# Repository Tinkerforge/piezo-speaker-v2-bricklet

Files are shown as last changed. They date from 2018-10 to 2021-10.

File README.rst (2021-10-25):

Piezo Speaker Bricklet 2.0
==========================

This repository contains the firmware source code and the hardware design
files. The documentation generator configs can be found at
https://github.com/Tinkerforge/generators

Repository Content
------------------

software/:
 * examples/: Examples for all supported languages
 * build/: Compiled files
 * src/: Source code of firmware
 * Makefile: Makefile to build project

hardware/:
 * Contains KiCad project files and additionally schematics as PDF

datasheets/:
 * Contains datasheets for sensors and complex ICs that are used

Hardware
--------

The hardware is designed with the open source EDA Suite KiCad
(http://www.kicad.org). Before you are able to open the files,
you have to install the Tinkerforge kicad-libraries
(https://github.com/Tinkerforge/kicad-libraries). You can either clone
them directly in hardware/ or clone them in a separate folder and
symlink them into hardware/
(ln -s kicad_path/kicad-libraries project_path/hardware). After that you
can open the .pro file in hardware/ with KiCad and from there view and
modify the schematics and the PCB layout.

Software
--------

If you want to do your own Brick/Bricklet firmware development we highly
recommend that you use our build environment setup script and read the
tutorial (https://www.tinkerforge.com/en/doc/Tutorials/Tutorial_Build_Environment/Tutorial.html).

To compile the C code we recommend you to install the newest GNU Arm Embedded
Toolchain (https://launchpad.net/gcc-arm-embedded/+download).
You also need to install bricklib2 (https://github.com/Tinkerforge/bricklib2).

You can either clone it directly in software/src/ or clone it in a
separate folder and symlink it into software/src/
(ln -s bricklib_path/bricklib2 project_path/software/src/). Finally make sure to
have CMake installed (http://www.cmake.org/cmake/resources/software.html).

After that you can build the firmware by invoking make in software/.
The firmware (.zbin) can then be found in software/build/ and uploaded
with brickv (click button "Flashing" on start screen).

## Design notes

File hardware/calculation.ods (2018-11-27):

LD1117
R (Ohm) | VOUT (V)
1000 | 5,0
470 | 3,0
220 | 2,1
100 | 1,6
LMR62014
R (Ohm) | VOUT (V)
34000 | 5,6
17000 | 9,9
11333,3333333333 | 14,3
8500 | 18,6

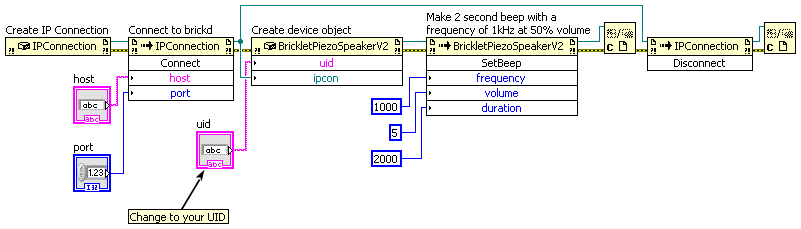
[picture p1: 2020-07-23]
software/examples/labview/Example Beep.vi.png

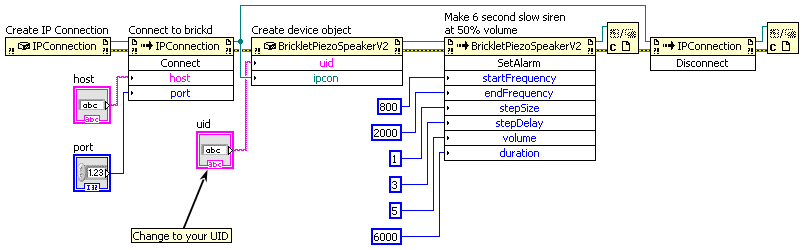
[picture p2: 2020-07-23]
software/examples/labview/Example Alarm.vi.png

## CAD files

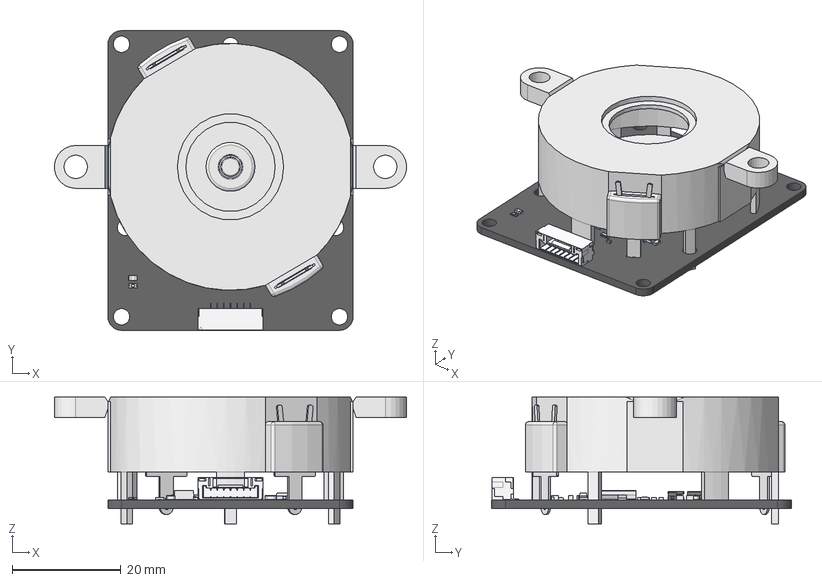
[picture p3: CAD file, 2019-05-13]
hardware/piezo-speaker-v2.FCStd
64.6 x 55.0 x 23.2 mm
Pcb
P4_PT_4532PLQ002_cp_5B86C3A8
C6_C_0603_5B86C852
C5_C_0805_5B86C837
C4_C_0603_5B86C222
C1_C_0402_5B86C258
C2_C_0805_5B86C2EB
C3_C_0603_5B86C321
C7_C_0805_5B86C0ED
C8_C_0603_5B86C4B9
C9_C_0805_5B86C3DE
C10_C_0805_5B86C2D0
D1_D_0603_blue_5B867174
D3_SOD-123_5B86C48A
L1_C_0603_5B86C7F5
L2_NR303_5B86C165
P1_BrickletConn_7pin_5B8671D7
R1_R_0603_5B86C6ED
R2_R_0603_5B86C69F
R3_R_0603_5B86C594
R4_R_0603_5B86C180
RP1_Cut_5B86C1A1
U1_QFN-24_4x4mm_Pitch0.5mm_5B86C357
U2_SOT-223_5B86C281
U3_SOT-23-5_5B86C10B
Q101_SOT23_5BD9AEDA
R101_R_0603_5BD9AEE4
R102_R_0603_5C406949
R103_R_0603_5C406953
R104_R_0603_5C40695D
R105_R_0603_5C406967
RP3_R_4x0603_5C40FF1B

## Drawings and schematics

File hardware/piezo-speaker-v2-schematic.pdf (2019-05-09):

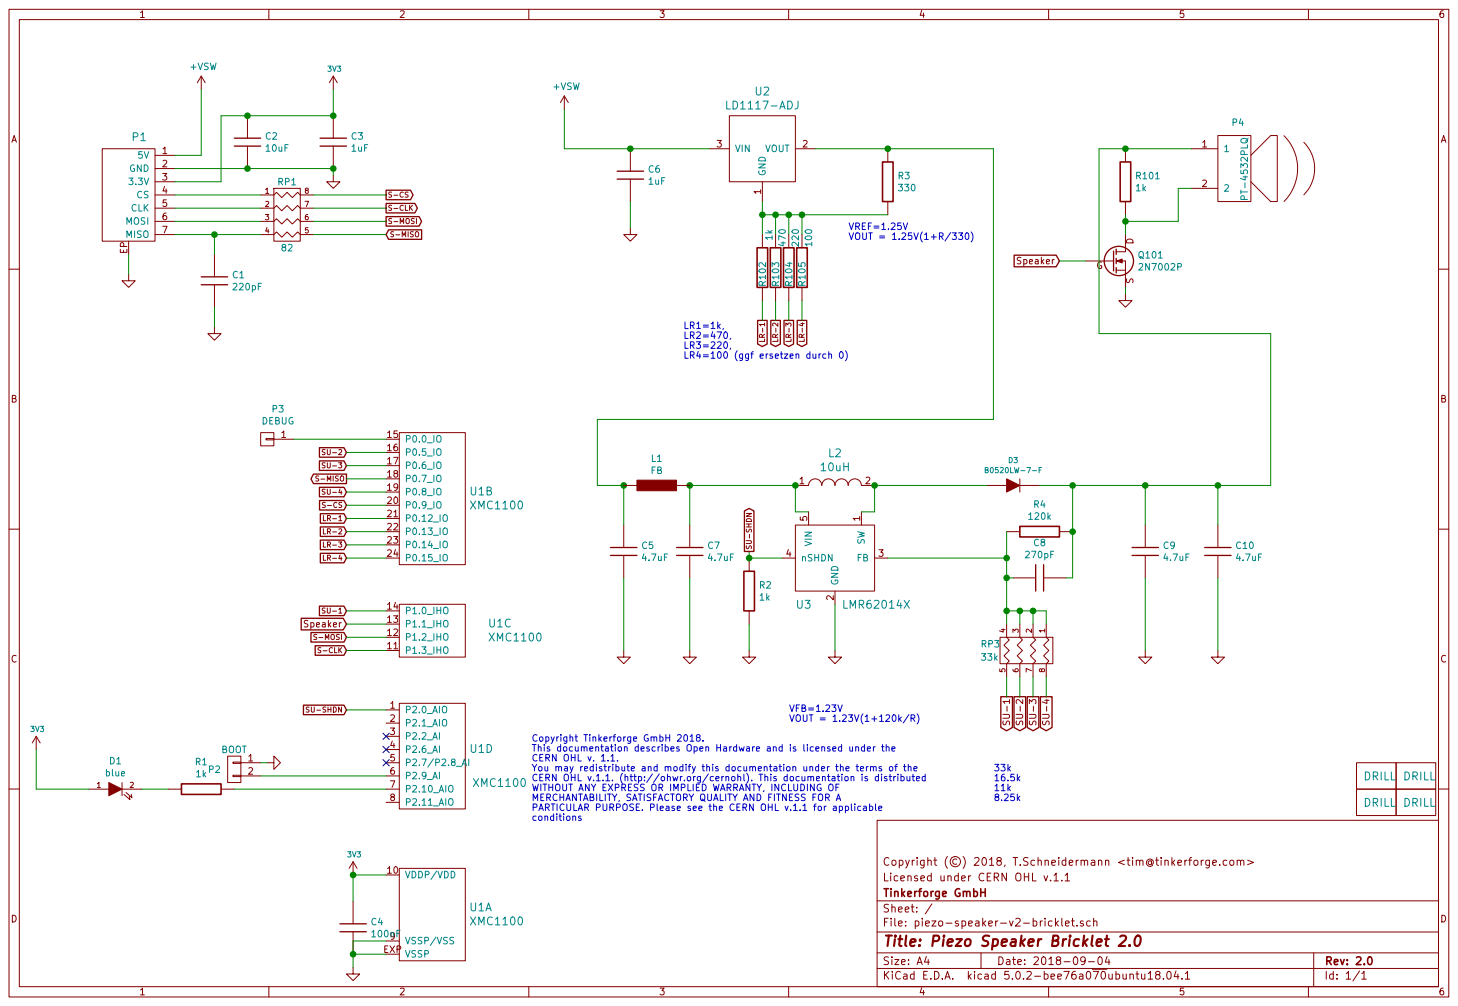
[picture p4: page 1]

This documentation describes Open Hardware and is licensed under the CERN OHL v. 1.1. You may redistribute and modify this documentation under the terms of the

CERN OHL v.1.1. (http://ohwr.org/cernohl). This documentation is distributed WITHOUT ANY EXPRESS OR IMPLIED WARRANTY, INCLUDING OF MERCHANTABILITY, SATISFACTORY QUALITY AND FITNESS FOR A

PARTICULAR PURPOSE. Please see the CERN OHL v.1.1 for applicable
conditions

Licensed under CERN OHL v.1.1 Copyright (©) 2018, T.Schneidermann <tim@tinkerforge.com>

File: piezo-speaker-v2-bricklet.sch Sheet: / Tinkerforge GmbH

Id: 1/1 Title: Piezo Speaker Bricklet 2.0

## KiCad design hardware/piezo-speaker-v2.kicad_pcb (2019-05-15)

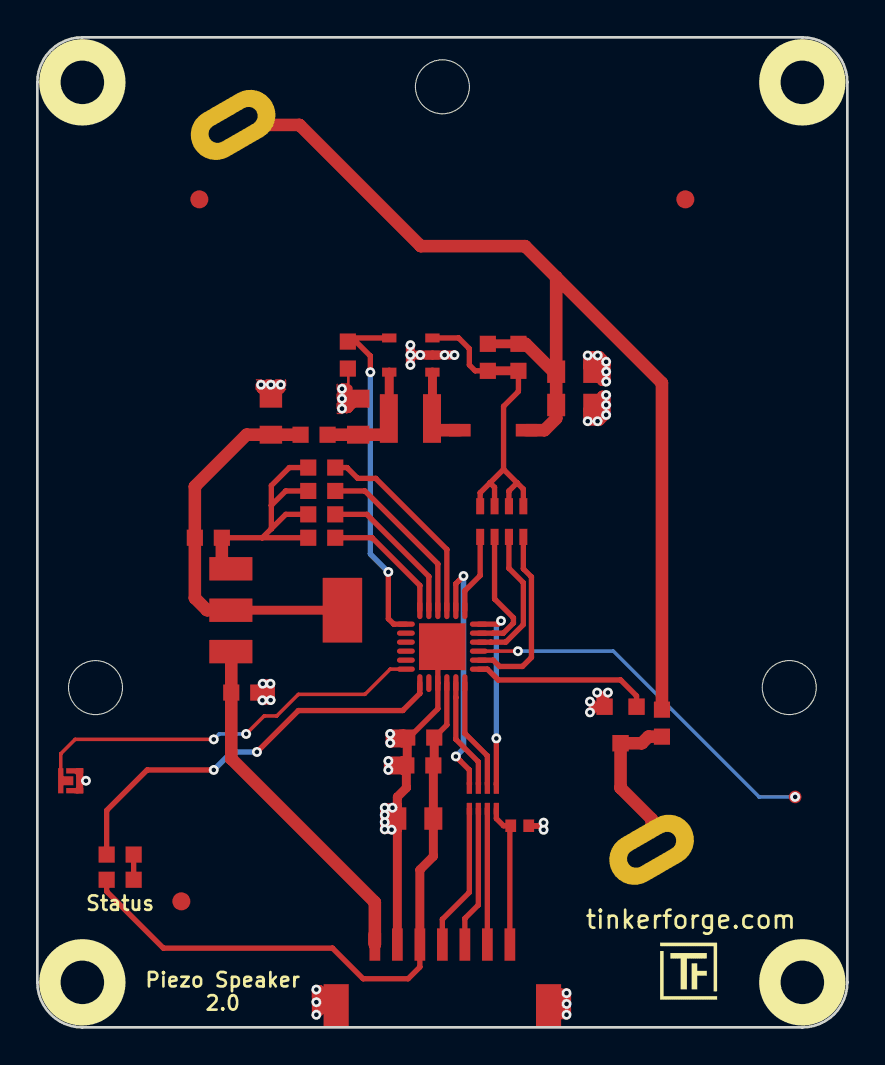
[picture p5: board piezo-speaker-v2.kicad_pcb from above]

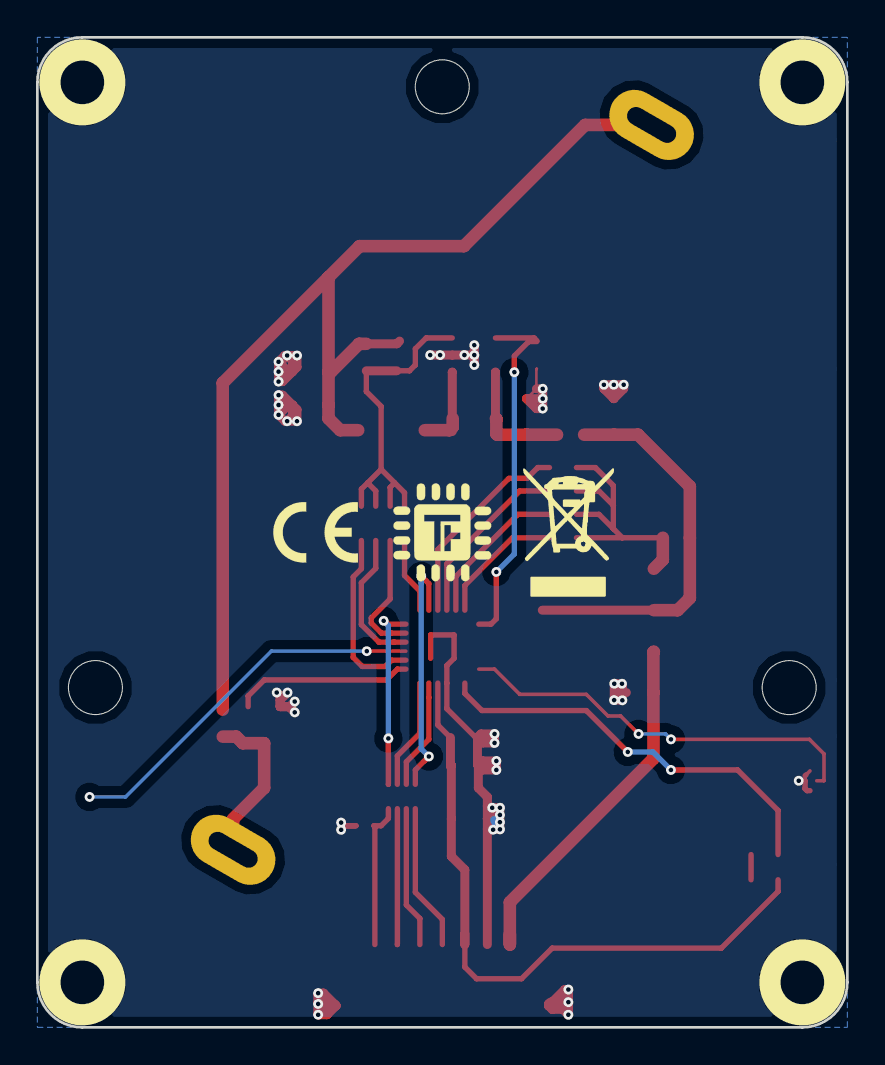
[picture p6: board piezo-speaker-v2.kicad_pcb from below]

Board: 2 copper layers, 45.0 x 55.0 mm, 42 parts (2 on the bottom side), 32 nets.

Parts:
C1: 220pF; C0402F
C2: 10uF; C0805
C3, C6: 1uF; C0603F
C4: 100nF; C0603F
C5, C7, C9, C10: 4.7uF; C0805
C8: 270pF; C0603F
D1: blue; D0603F
D3: B0520LW-7-F; SOD-123
Fiducial_Mark: VAL**; Fiducial_Mark
Fiducial_Mark#2, Fiducial_Mark#3: VAL**; Fiducial_Mark
L1: FB; C0603F
L2: 10uH; NR3030
P1: CON-SENSOR2
P2: BOOT; SolderJumper
P3: DEBUG; DEBUG_PAD
P4: PT-4532PLQ
Q101: 2N7002P; SOT23GDS
R1, R2, R101, R102: 1k; R0603F
R3: 330; R0603F
R4: 120k; R0603F
R103: 470; R0603F
R104: 220; R0603F
R105: 100; R0603F
RP1: 82; 4X0402
RP3: 33k; 4X0603
U1: XMC1100; QFN24-4x4mm-0.5mm
U2: LD1117-ADJ; SOT-223
U3: LMR62014X; SOT23-5
U4, U5, U6, U7: DRILL; DRILL_NP
VAL: WEEE_7mm
VAL#2: CE_5mm

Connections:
3V3: C2.1, C3.1, C4.1, D1.1, P1.3, U1.10
+VSW: C6.1, P1.1, U2.3
GND: C1.2, C2.2, C3.2, C4.2, C5.2, C6.2, C7.2, C9.2, C10.2, P1.2, P1.EP, P2.1, Q101.S, R2.2, U1.9, U1.EXP, U3.2
LR-1: R102.2, U1.21
LR-2: R103.2, U1.22
LR-3: R104.2, U1.23
LR-4: R105.2, U1.24
unnamed: C1.1, P1.7, RP1.4
unnamed: C5.1, L1.2, R3.1, U2.2
unnamed: C7.1, L1.1, L2.1, U3.5
unnamed: C8.2, R4.2, RP3.1, RP3.2, RP3.3, RP3.4, U3.3
unnamed: C8.1, C9.1, C10.1, D3.2, P4.1, R4.1, R101.1
unnamed: D1.2, R1.2
unnamed: D3.1, L2.2, U3.1
unnamed: P1.4, RP1.1
unnamed: P1.5, RP1.2
unnamed: P1.6, RP1.3
unnamed: P2.2, U1.6
unnamed: P3.1, U1.15
unnamed: P4.2, Q101.D, R101.2
unnamed: R1.1, U1.7
unnamed: R3.2, R102.1, R103.1, R104.1, R105.1, U2.1
S-CLK: RP1.7, U1.11
S-CS: RP1.8, U1.20
S-MISO: RP1.5, U1.18
S-MOSI: RP1.6, U1.12
SU-1: RP3.5, U1.14
SU-2: RP3.6, U1.16
SU-3: RP3.7, U1.17
SU-4: RP3.8, U1.19
SU-SHDN: R2.1, U1.1, U3.4
Speaker: Q101.G, U1.13

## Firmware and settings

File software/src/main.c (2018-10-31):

/* piezo-speaker-v2-bricklet
 * Copyright (C) 2018 Olaf Lüke <olaf@tinkerforge.com>
 *
 * main.c: Initialization for Piezo Speaker Bricklet 2.0
 *
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
 * You should have received a copy of the GNU Lesser General Public
 * License along with this library; if not, write to the
 * Free Software Foundation, Inc., 59 Temple Place - Suite 330,
 * Boston, MA 02111-1307, USA.
 */

#include <stdio.h>
#include <stdbool.h>

#include "configs/config.h"

#include "bricklib2/bootloader/bootloader.h"
#include "bricklib2/hal/system_timer/system_timer.h"
#include "bricklib2/logging/logging.h"
#include "communication.h"
#include "speaker.h"

int main(void) {
	logging_init();
	logd("Start Piezo Speaker Bricklet 2.0\n\r");

	communication_init();
	speaker_init();

	while(true) {
		bootloader_tick();
		communication_tick();
		speaker_tick();
	}
}

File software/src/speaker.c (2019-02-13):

/* piezo-speaker-v2-bricklet
 * Copyright (C) 2018 Olaf Lüke <olaf@tinkerforge.com>
 *
 * speaker.c: Driver for speaker
 *
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
 * You should have received a copy of the GNU Lesser General Public
 * License along with this library; if not, write to the
 * Free Software Foundation, Inc., 59 Temple Place - Suite 330,
 * Boston, MA 02111-1307, USA.
 */

#include "speaker.h"

#include "configs/config_speaker.h"

#include "bricklib2/utility/util_definitions.h"
#include "bricklib2/hal/ccu4_pwm/ccu4_pwm.h"
#include "bricklib2/hal/system_timer/system_timer.h"

#include "communication.h"

#define SPEAKER_PIN_NUM 8

#define SPEAKER_PIN_VALUE_LOW   0
#define SPEAKER_PIN_VALUE_HIGH  1
#define SPEAKER_PIN_VALUE_FLOAT 2

const XMC_GPIO_CONFIG_t speaker_config_low = {
	.mode                = XMC_GPIO_MODE_OUTPUT_PUSH_PULL,
	.output_level        = XMC_GPIO_OUTPUT_LEVEL_LOW,
};

const XMC_GPIO_CONFIG_t speaker_config_high = {
	.mode                = XMC_GPIO_MODE_OUTPUT_PUSH_PULL,
	.output_level        = XMC_GPIO_OUTPUT_LEVEL_HIGH,
};

const XMC_GPIO_CONFIG_t speaker_config_float = {
	.mode                = XMC_GPIO_MODE_INPUT_TRISTATE,
	.input_hysteresis    = XMC_GPIO_INPUT_HYSTERESIS_STANDARD,
};

typedef struct {
	XMC_GPIO_PORT_t *port;
	uint8_t pin;
} SpeakerPin;

SpeakerPin speaker_pins[SPEAKER_PIN_NUM] = {
	{SPEAKER_LR0_PIN}, {SPEAKER_LR1_PIN}, {SPEAKER_LR2_PIN}, {SPEAKER_LR3_PIN},
	{SPEAKER_SU0_PIN}, {SPEAKER_SU1_PIN}, {SPEAKER_SU2_PIN}, {SPEAKER_SU3_PIN},
};

Speaker speaker;

// Volume bitmask for 11 different volume levels:
// bit 8          | bit 7 | bit 6 | bit 5 | bit 4 | bit 3 | bit 2 | bit 1 | bit 0
// Enable Step-Up | SU3   | SU2   | SU1   | SU0   | LR3   | LR2   | LR1   | LR0
const uint16_t speaker_volume[11] = {
	0b011110000, // 1.55V LR
	0b011110111, // 1.86V LR
	0b011111010, // 2.10V LR
	0b011111011, // 2.32V LR
	0b011111100, // 2.60V LR
	0b011111101, // 3.28V LR
	0b011111110, // 3.88V LR
	0b101111110, // 5.7V  SU
	0b100111110, // 10.1V SU
	0b100011110, // 14.6V SU
	0b100001110, // 19.1V SU
};

void speaker_set_pin(uint8_t pin, uint8_t value) {
	switch(value) {
		case SPEAKER_PIN_VALUE_LOW:   XMC_GPIO_Init(speaker_pins[pin].port, speaker_pins[pin].pin, &speaker_config_low);   break;
		case SPEAKER_PIN_VALUE_HIGH:  XMC_GPIO_Init(speaker_pins[pin].port, speaker_pins[pin].pin, &speaker_config_high);  break;
		case SPEAKER_PIN_VALUE_FLOAT: XMC_GPIO_Init(speaker_pins[pin].port, speaker_pins[pin].pin, &speaker_config_float); break;
	}

}

void speaker_set_frequency(const uint32_t frequency) {
	if(frequency == 0) {
		XMC_GPIO_Init(SPEAKER_PWM_PIN, &speaker_config_low);
		speaker.pwm_is_init = false;
	} else {
		uint32_t period = MIN(1000000/frequency, UINT16_MAX);
		if(speaker.pwm_is_init) {
			ccu4_pwm_set_period(SPEAKER_PWM_SLICE, period);
		} else {
			ccu4_pwm_init(SPEAKER_PWM_PIN, SPEAKER_PWM_SLICE, period);
			speaker.pwm_is_init = true;
		}
		ccu4_pwm_set_duty_cycle(SPEAKER_PWM_SLICE, period/2);
	}
}

void speaker_update_volume(void) {
	uint16_t volume_bitmask = speaker_volume[MIN(10, speaker.volume)];
	for(uint8_t i = 0; i < 8; i++) {
		if(volume_bitmask & (1 << i)) {
			speaker_set_pin(i, SPEAKER_PIN_VALUE_FLOAT);
		} else {
			speaker_set_pin(i, SPEAKER_PIN_VALUE_LOW);
		}
	}

	if(volume_bitmask & (1 << 8)) {
		XMC_GPIO_SetOutputHigh(SPEAKER_SUS_PIN);
	} else {
		XMC_GPIO_SetOutputLow(SPEAKER_SUS_PIN);
	}
}

void speaker_init(void) {
	memset(&speaker, 0, sizeof(Speaker));

	speaker.beep_frequency = 1000;
	speaker.beep_duration = 1000;

	XMC_GPIO_Init(SPEAKER_SUS_PIN, &speaker_config_low);

	speaker_set_frequency(0);
	speaker_update_volume();

}

void speaker_tick(void) {
	if((speaker.beep_start_time != 0) && system_timer_is_time_elapsed_ms(speaker.beep_start_time, speaker.beep_duration)) {
		if(speaker.beep_duration != PIEZO_SPEAKER_V2_BEEP_DURATION_INFINITE) {
			speaker_set_frequency(0);
			speaker.beep_start_time = 0;
			speaker.beep_done = true;
		}
	}

	if((speaker.alarm_start_time != 0) && system_timer_is_time_elapsed_ms(speaker.alarm_start_time, speaker.alarm_duration)) {
		if(speaker.alarm_duration != PIEZO_SPEAKER_V2_ALARM_DURATION_INFINITE) {
			speaker_set_frequency(0);
			speaker.alarm_start_time = 0;
			speaker.alarm_done = true;
		}
	}

	if(speaker.alarm_start) {
		if(speaker.beep_start_time != 0) {
			speaker.beep_start_time = 0;
			speaker.beep_done = true;
		}

		speaker_update_volume();

		speaker.alarm_start = false;
		speaker.alarm_start_time = system_timer_get_ms();
		speaker.alarm_last_time = system_timer_get_ms();

		speaker.alarm_current_frequency = speaker.alarm_start_frequency;
		speaker.alarm_direction = 1;
		if(speaker.alarm_duration != 0) {
			speaker_set_frequency(speaker.alarm_current_frequency);
		} else {
			speaker_set_frequency(0);
			speaker.alarm_start_time = 0;
		}
	}

	if(speaker.alarm_start_time != 0) {
		if(system_timer_is_time_elapsed_ms(speaker.alarm_last_time, speaker.alarm_step_delay)) {
			speaker.alarm_last_time += speaker.alarm_step_delay;
			speaker.alarm_current_frequency += speaker.alarm_direction*speaker.alarm_step_size;
			if((speaker.alarm_current_frequency > speaker.alarm_end_frequency) || 
			   (speaker.alarm_current_frequency < speaker.alarm_start_frequency)) {
				speaker.alarm_direction *= -1;
				speaker.alarm_current_frequency += speaker.alarm_direction*speaker.alarm_step_size;
			}

			speaker_set_frequency(speaker.alarm_current_frequency);
		}
	}
	
	if(speaker.beep_start) {
		if(speaker.alarm_start_time != 0) {
			speaker.alarm_start_time = 0;
			speaker.alarm_done = true;
		}

		speaker_update_volume();

		speaker.beep_start = false;
		if(speaker.beep_duration != 0) {
			speaker.beep_start_time = system_timer_get_ms();
			speaker_set_frequency(speaker.beep_frequency);
		} else {
			speaker.beep_start_time = 0;
			speaker_set_frequency(0);
		}
	}

}

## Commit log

2018-08-29 created schematics
    [piezo-speaker-v2-bricklet.sch]
2018-08-29 created pcb layout
    [piezo-speaker-v2-bricklet.kicad_pcb, piezo-speaker-v2-bricklet.sch]
2018-08-29 changed pcb design
    [piezo-speaker-v2-bricklet.kicad_pcb]
2018-08-29 final pcb design (ready for prototype)
    [piezo-speaker-v2-bricklet.kicad_pcb]
2018-09-04 improve some fiducials, add text
    [piezo-speaker-v2-bricklet.kicad_pcb, piezo-speaker-v2-bricklet.sch]
2018-09-18 fix outline
    [piezo-speaker-v2-bricklet.kicad_pcb]
2018-09-18 changed the PT footprint, logos, erase and debug pin and first moved the first cap
    [piezo-speaker-v2-bricklet.kicad_pcb]
2018-09-18 changed R4 from 118k to 120k
    [piezo-speaker-v2-bricklet.sch]
2018-10-04 add hints
    [piezo-speaker-v2-bricklet.sch]
2018-10-31 Add initial stub implementation
    [cmake_config_custom.txt]
2018-10-31 fix schematic, add 2n7002p, change pins
    [piezo-speaker-v2-bricklet.kicad_pcb, piezo-speaker-v2-bricklet.sch]
2018-10-31 fix schematic, pcb not fixed
    [piezo-speaker-v2-bricklet.kicad_pcb, piezo-speaker-v2-bricklet.sch]
2018-11-27 change prototype resistor values
    [calculation.ods, piezo-speaker-v2-bricklet.sch]
2018-11-27 update resistor values
    [piezo-speaker-v2-bricklet.sch]
2019-01-22 fix bugs
    [piezo-speaker-v2-bricklet.kicad_pcb, piezo-speaker-v2-bricklet.sch]
2019-01-22 drc, change bottom copper plane
    [piezo-speaker-v2-bricklet.kicad_pcb]
2019-02-06 specify rp3 to 33k
    [piezo-speaker-v2-bricklet.kicad_pcb, piezo-speaker-v2-bricklet.sch]
2019-02-21 add fiducial marks
    [piezo-speaker-v2-bricklet.kicad_pcb]
2019-02-22 changed processor to XMC1100
    [piezo-speaker-v2-bricklet.kicad_pcb, piezo-speaker-v2-bricklet.sch]
2019-02-26 specify ld1117-adj
    [piezo-speaker-v2-bricklet.kicad_pcb, piezo-speaker-v2-bricklet.sch]
2019-05-07 Apply bootloader pointer end fix to all new Bricklets
    [config_custom_bootloader.h]
2019-05-09 add schematic
    [piezo-speaker-v2-bricklet.sch]
2019-05-10 add cutout information
    [piezo-speaker-v2-bricklet.kicad_pcb]
2019-05-13 add 3d model of speaker
    [piezo-speaker-v2-bricklet.kicad_pcb]
2019-05-13 add 3d data
    [piezo-speaker-v2-bricklet.FCStd, piezo-speaker-v2-bricklet.kicad_pcb]
2019-05-13 fix file names
    [piezo-speaker-v2.FCStd, piezo-speaker-v2.kicad_pcb, piezo-speaker-v2.sch]
2019-05-15 add correct drills
    [piezo-speaker-v2.kicad_pcb, piezo-speaker-v2.sch]
2020-09-02 uc: Add example driver note.
2021-10-25 Update KiCad link
    https://www.kicad.org/blog/2021/10/Avoid-links-to-former-kicad-domain/

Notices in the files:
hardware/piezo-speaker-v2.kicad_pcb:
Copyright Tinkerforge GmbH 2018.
